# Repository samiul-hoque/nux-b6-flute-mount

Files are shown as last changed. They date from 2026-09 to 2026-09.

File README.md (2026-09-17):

# NUX B-6 flute mount

3D printed clamps that mount a **NUX B-6** or **B-6 Pro** wireless microphone onto a
flute or tin whistle.

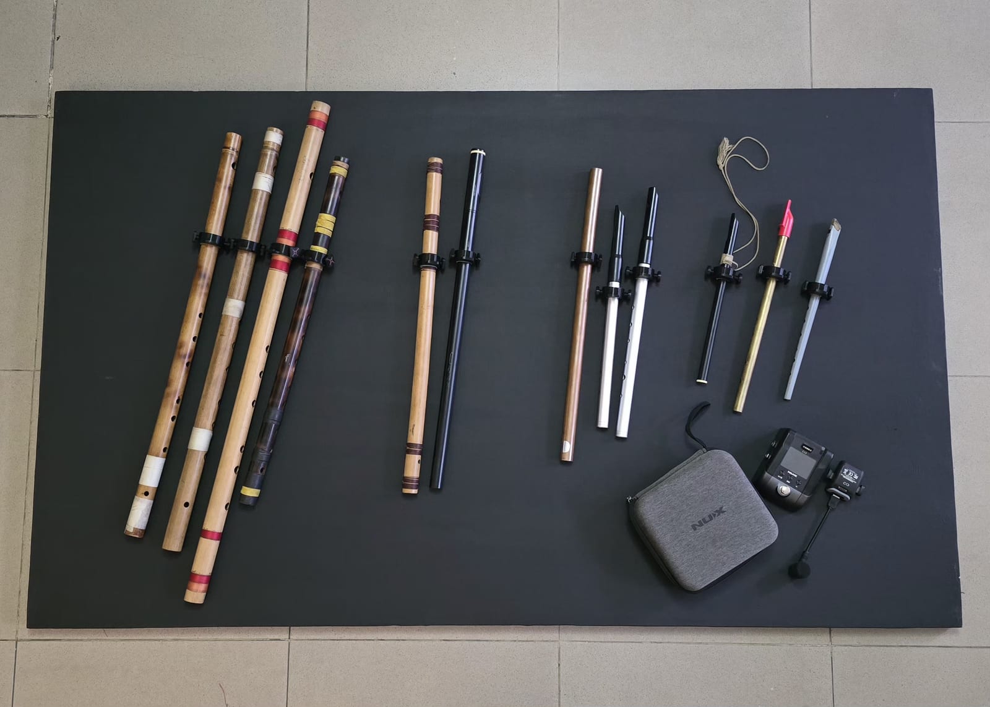
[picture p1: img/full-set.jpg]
Thirteen flutes with clamps fitted, alongside the NUX B-6 case and transmitter


*The set this was built for: thirteen flutes in bamboo, aluminium, copper, brass and
resin, each with a clamp fitted, and the B-6 kit bottom right.*

The B-6 is sold for saxophone. It expects to clamp onto a bell: a rigid flared metal mouth
of one known size. A flute is a straight tube, and if you play one there is nothing on the
instrument for the mic to hold. These parts sit between the two.

The clamp is in two layers, which is the whole idea:

- a **rigid PETG split ring** that carries the standard B-6 clip and provides the clamping
  force, closed with a printed thumb screw that threads straight into the ring
- a **flexible TPU spacer** that takes up the difference between the clamp bore and your
  actual tube, and grips without marking the instrument

| | |
| --- | --- |
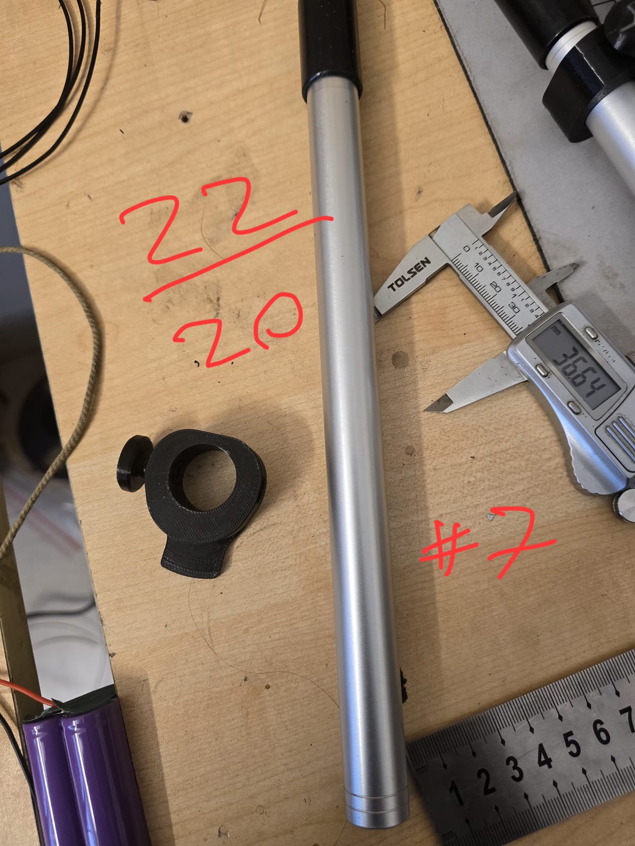
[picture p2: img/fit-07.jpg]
The printed clamp on its own, on a workbench beside an aluminium flute and callipers
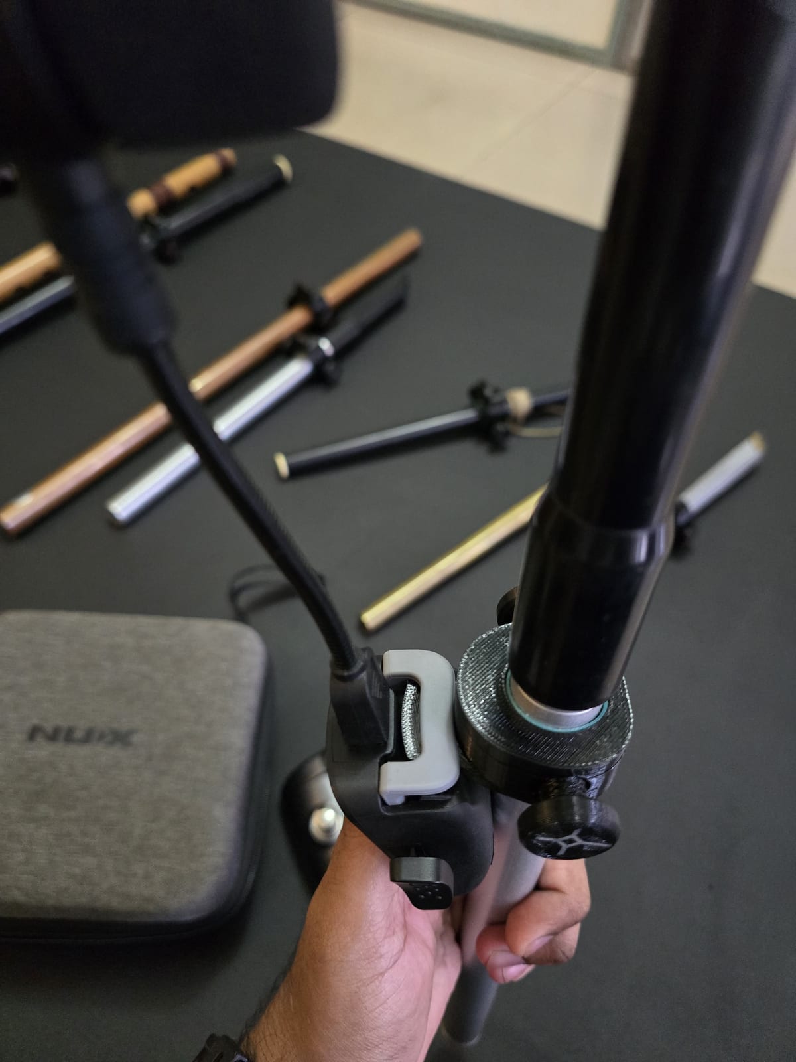
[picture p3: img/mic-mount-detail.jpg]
Close view of the clamp holding the NUX mic clip with the TPU spacer visible inside the bore
|  |  |
| The rigid part on its own: split ring, mic boss underneath, printed thumb screw. | Assembled. The pale ring inside the bore is the TPU spacer; the boss takes the B-6 clip. |

Keeping those separate is what makes one clamp cover several flutes. A rigid clamp
tightened straight onto a bamboo flute would slip or dent it, and onto a thin aluminium
tube it would crush it. The TPU does the conforming so the PETG does not have to.

Built in a day for Nazm Anwr, who plays flute for the Bangladeshi band
[Kaaktaal](https://samiulmakes.com/projects/flute-mic-clamps/), because he performs with
thirteen flutes and swaps between them mid-set. The screws are printed too: no hardware
run, nothing metal to lose in a green room, and a thumb screw big enough to turn by hand
between songs.

Full write-up, with photos of the whole set:
**<https://samiulmakes.com/projects/flute-mic-clamps/>**

## Sizes

Five clamp bores, ten spacers. Pick the clamp that fits over your flute, then the spacer
that brings it down to your diameter.

| Clamp bore | Spacer inner diameters |
| --- | --- |
| 22 mm | 15, 16, 20 |
| 24 mm | 22, 22.5 |
| 28 mm | 24.5, 26.5 |
| 30 mm | 27.5 |
| 35 mm | 30, 33 |

Measure your flute with callipers at the point you want the mic to sit, which is usually
just below the embouchure hole and clear of the finger holes.

## Instruments these have been fitted to

The set these were built for is mostly handmade bamboo, which has no model number. The
shop-bought instruments in it do:

| Instrument | Material |
| --- | --- |
| Tony Dixon DX207, key of A | Aluminium |
| Tony Dixon DX207, key of G | Aluminium |
| Tony Dixon TB014 tenor flute | Polymer |
| Tony Dixon DX001 soprano whistle | Polymer |
| Generation whistle, key of Eb | Brass |
| Clarke whistle, key of C | Tin |

If you play one of these, a clamp and spacer from this repo has been fitted to that exact
instrument. **Measure yours before printing anyway.** The pairings were recorded per flute
during the fitting session, not per model, so there is no "a DX207 takes 22 over 20" list
to give you — and tube stock changes between production runs.

## If your flute is between sizes

You need a **new spacer, not a new clamp**. Take the clamp bore above your diameter, open
the CAD, change the spacer's inner diameter, print it. That is a one-parameter change and
a few minutes of printing.

Which is the reason the source file is here and not just the STLs.

## Printing

| Part | Material | Layer height | Walls |
| --- | --- | --- | --- |
| Clamp shells | PETG | 0.2 mm | 4 |
| Thumb screws | PETG | 0.2 mm | 4 |
| Spacers | TPU | 0.2 mm | — |

Four walls on the PETG is the one setting worth keeping. The clamp is a split ring that
gets tightened onto an instrument, so the load runs straight through the wall either side
of the screw; thin walls there are where it would fail. The originals have been through a
live set and are still in use on these settings.

Everything else is whatever your printer likes. Print the screws standing on their heads,
threads upward, so the thread does not need support.

<!-- TODO (Samiul): infill and TPU shore hardness still not recorded. -->

## Fasteners

The clamp closes with printed thumb screws, in three shank lengths:

| Part | Shank |
| --- | --- |
| `screw-6mm.stl` | 6 mm |
| `screw-8mm.stl` | 8 mm |
| `screw-10mm.stl` | 10 mm |

All three share the same head: a 20 mm disc, 5 mm thick, with knurl lobes standing out to
25 mm so it can be turned with cold fingers. The thread is a printed one, roughly 10 mm
across, not an M-series profile — these mate with the clamps here and with nothing else.

There is no nut. The thread is cut into the clamp itself, so the screw is the only
fastener you print.

Longer shanks are for the bigger bores, where the split has further to close. If you are
unsure, print the 8 mm first.

## Files

`cad/flute-adapter-v19.f3d` — the parametric Fusion 360 source for the clamps and
spacers, and the file you want if your flute is not on the list.

`cad/screws-v5.f3d` — the Fusion source for the thumb screws.

`stl/` — 18 parts, ready to print:

| Clamp | Spacers |
| --- | --- |
| `clamp-22mm.stl` | `spacer-22-to-15mm.stl`, `spacer-22-to-16mm.stl`, `spacer-22-to-20mm.stl` |
| `clamp-24mm.stl` | `spacer-24-to-22mm.stl`, `spacer-24-to-22.5mm.stl` |
| `clamp-28mm.stl` | `spacer-28-to-24.5mm.stl`, `spacer-28-to-26.5mm.stl` |
| `clamp-30mm.stl` | `spacer-30-to-27.5mm.stl` |
| `clamp-35mm.stl` | `spacer-35-to-30mm.stl`, `spacer-35-to-33mm.stl` |

Plus three thumb screws — `screw-6mm.stl`, `screw-8mm.stl`, `screw-10mm.stl` — which fit
every clamp. See [Fasteners](#fasteners).

Every spacer is 18 mm tall, so it sits fully inside the clamp it belongs to. A spacer only
fits its own clamp; the outer profile changes with the bore.

## Licence

[Creative Commons Attribution 4.0 International](LICENSE) (CC BY 4.0).

Use these however you like — print them, sell the prints, modify the CAD, put the
modified version out yourself — as long as you credit me. Something along these lines is
enough:

> Flute mic clamps for the NUX B-6 by [Samiul Hoque](https://samiulmakes.com), licensed
> CC BY 4.0. <https://github.com/samiul-hoque/nux-b6-flute-mount>

If you remix them, say what you changed, so nobody chasing a bad fit ends up at my door
over someone else's edit.

## In use

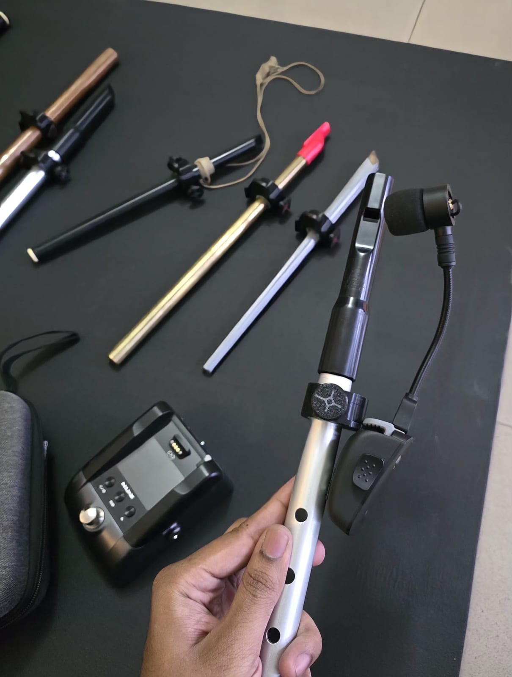
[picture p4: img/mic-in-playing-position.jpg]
A small aluminium flute held in playing position with the clamp, transmitter and gooseneck mic mounted


*The mic head sitting where it needs to sit, on a flute that had nowhere to mount
anything. These held up through a live set and are still in use.*

## Credits

Designed by [Samiul Hoque](https://samiulmakes.com) with Nazm Anwr.
NUX and B-6 are trademarks of their respective owner; this project is not affiliated with
or endorsed by NUX.

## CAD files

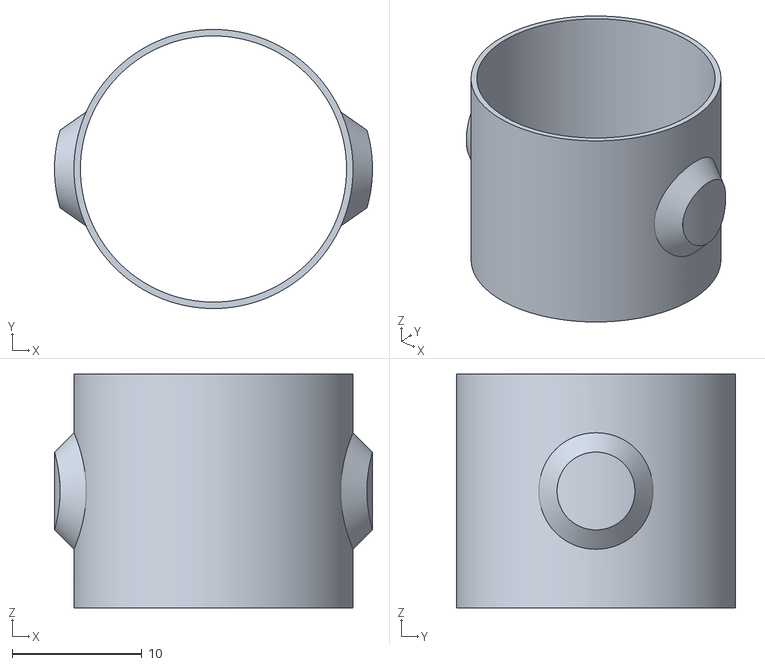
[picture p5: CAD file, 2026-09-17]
stl/spacer-22-to-20mm.stl
24.5 x 21.5 x 18.0

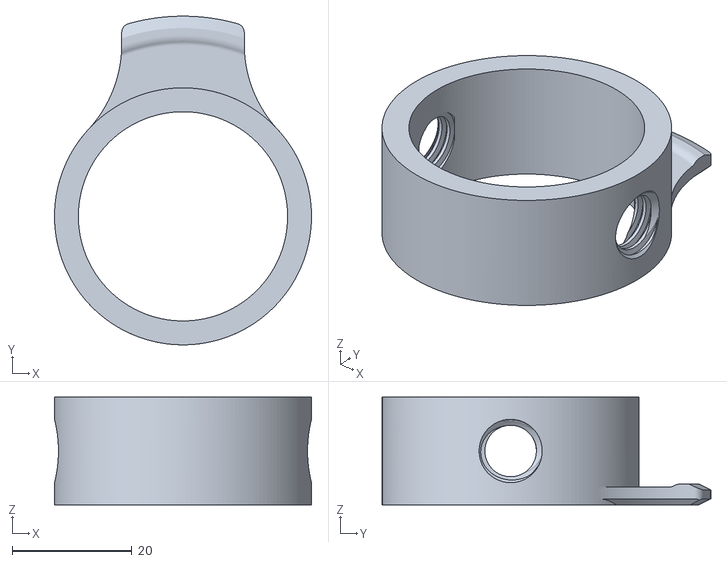
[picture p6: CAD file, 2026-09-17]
stl/clamp-35mm.stl
43.0 x 55.0 x 18.0

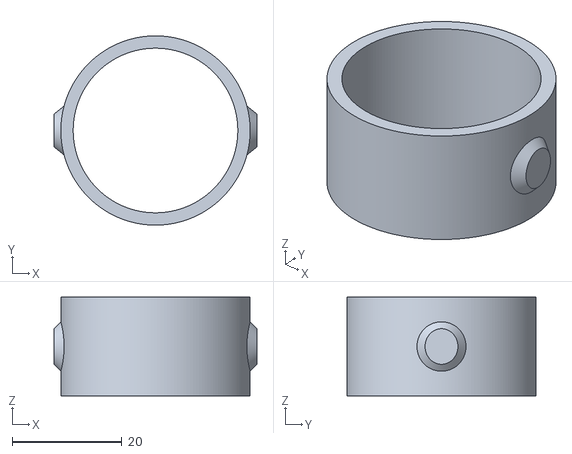
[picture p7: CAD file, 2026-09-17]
stl/spacer-35-to-30mm.stl
37.0 x 34.5 x 18.0

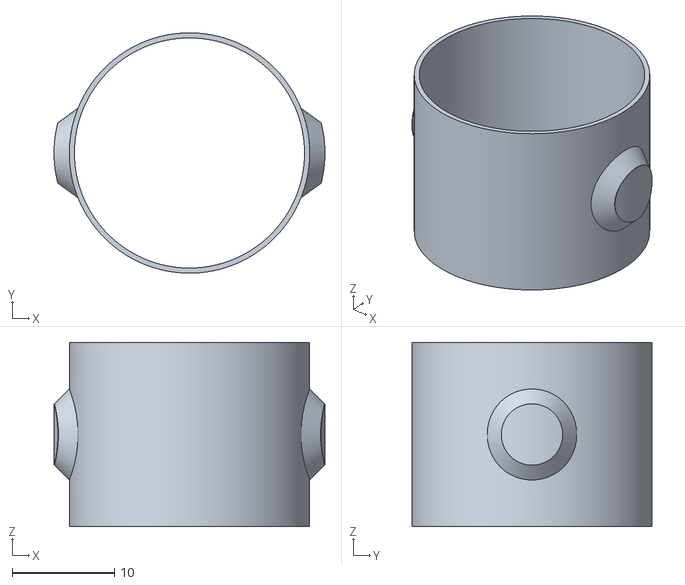
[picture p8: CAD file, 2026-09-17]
stl/spacer-24-to-22.5mm.stl
26.5 x 23.5 x 18.0

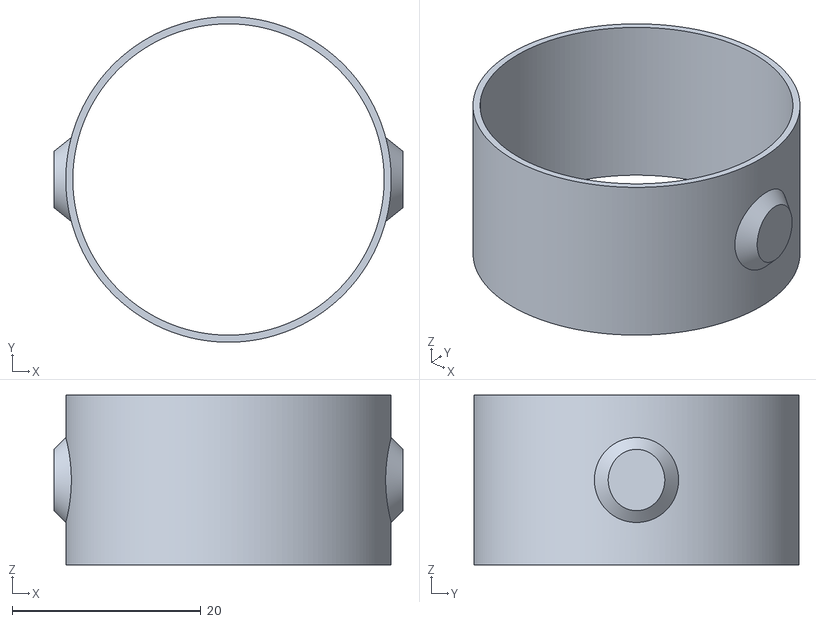
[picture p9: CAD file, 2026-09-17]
stl/spacer-35-to-33mm.stl
37.0 x 34.5 x 18.0

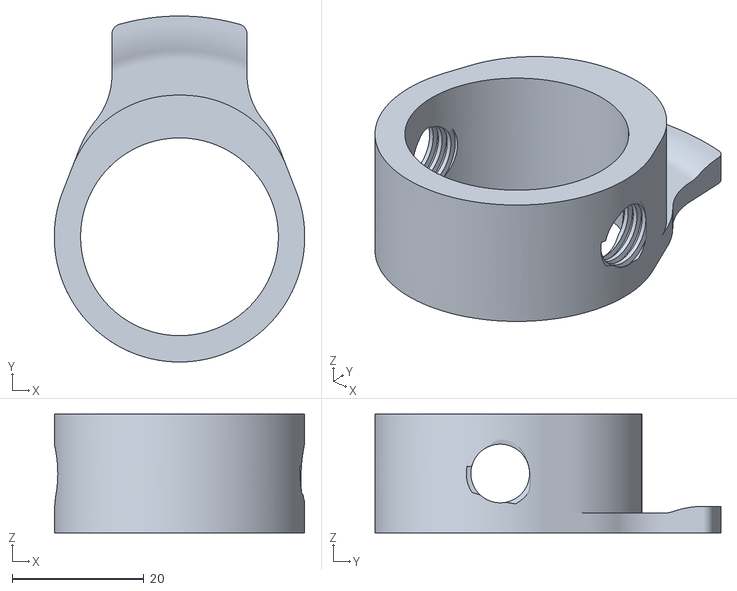
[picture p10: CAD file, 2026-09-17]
stl/clamp-30mm.stl
38.0 x 52.5 x 18.0

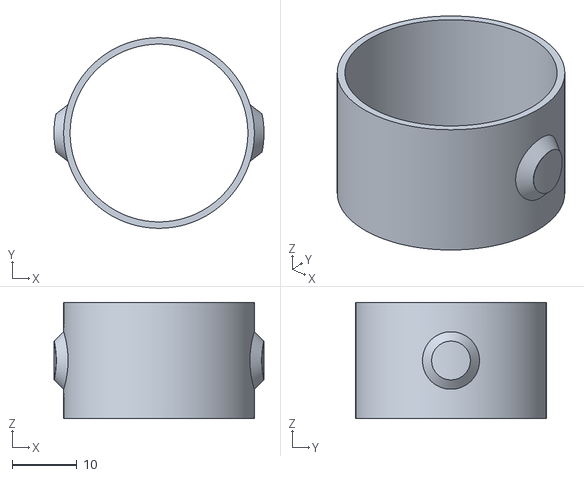
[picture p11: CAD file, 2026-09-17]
stl/spacer-30-to-27.5mm.stl
32.5 x 29.5 x 18.0

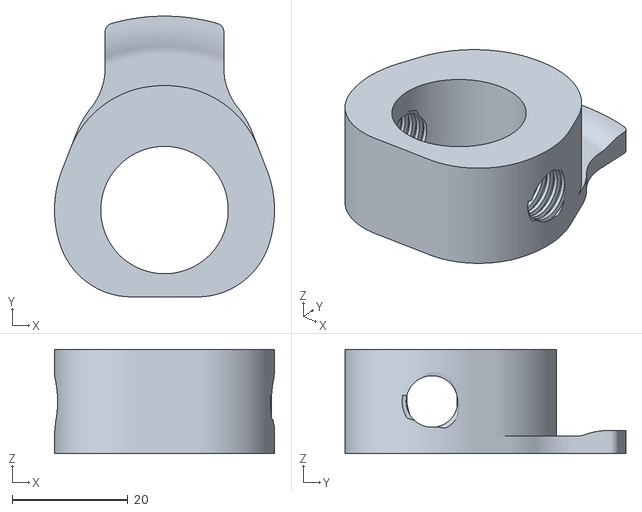
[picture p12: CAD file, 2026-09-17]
stl/clamp-22mm.stl
38.0 x 48.5 x 18.0

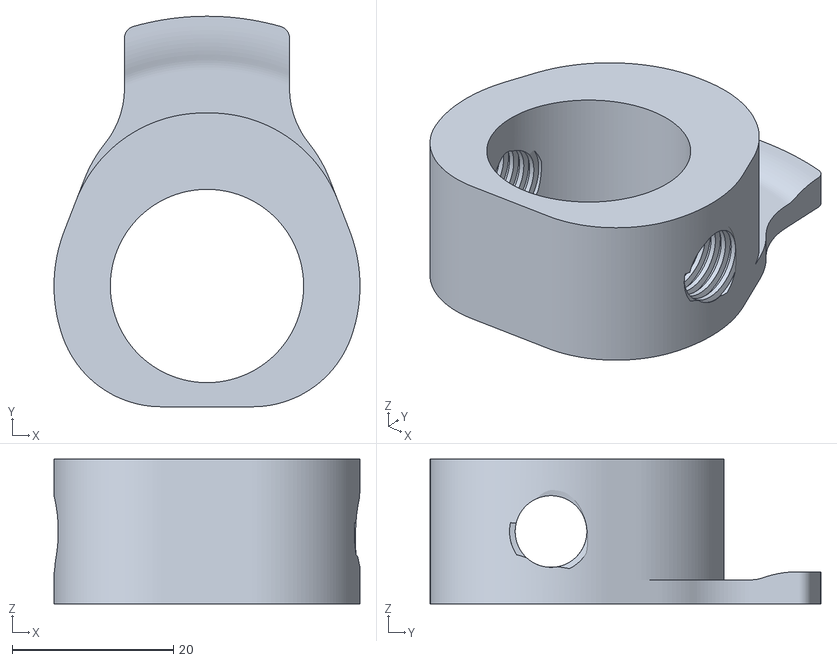
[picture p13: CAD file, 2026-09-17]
stl/clamp-24mm.stl
38.0 x 48.5 x 18.0

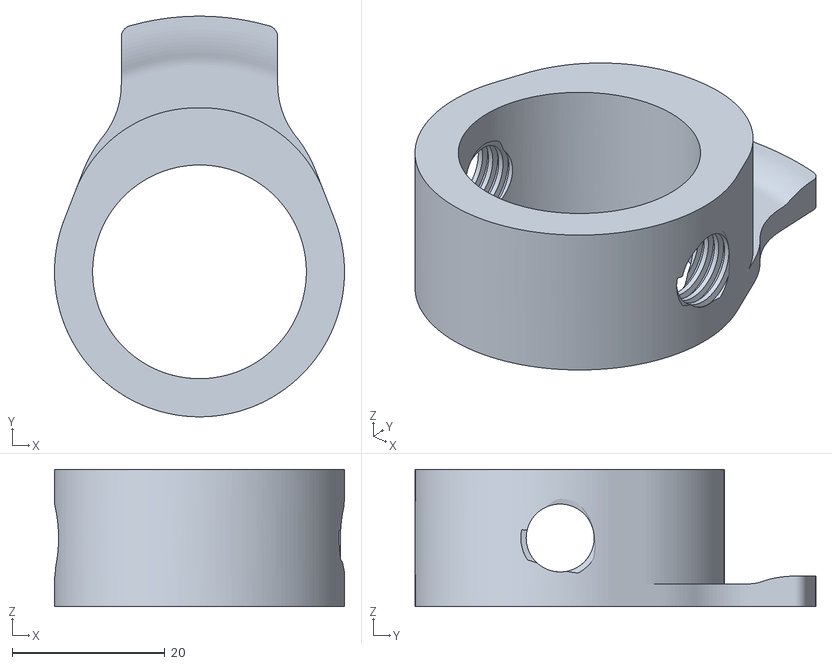
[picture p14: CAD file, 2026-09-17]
stl/clamp-28mm.stl
38.0 x 52.5 x 18.0

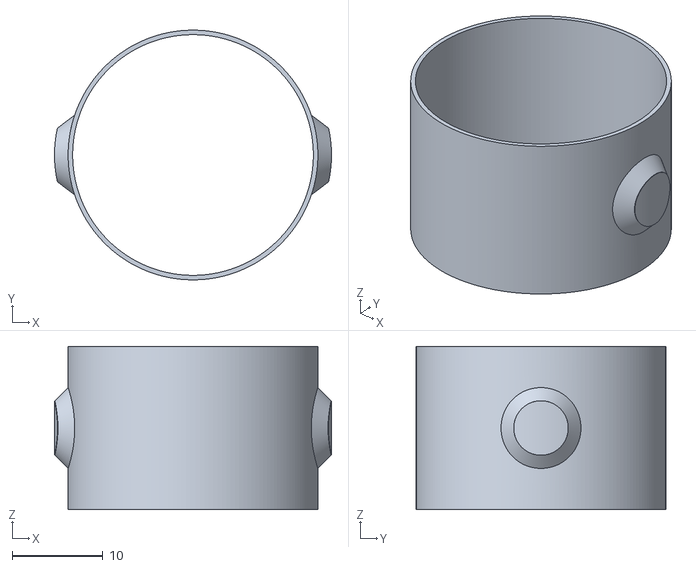
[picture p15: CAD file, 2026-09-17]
stl/spacer-28-to-26.5mm.stl
30.5 x 27.5 x 18.0

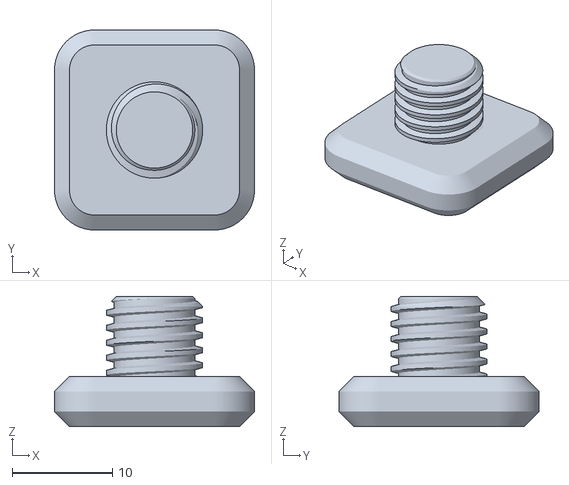
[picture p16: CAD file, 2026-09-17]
stl/screw-8mm.stl
20.0 x 20.0 x 13.0

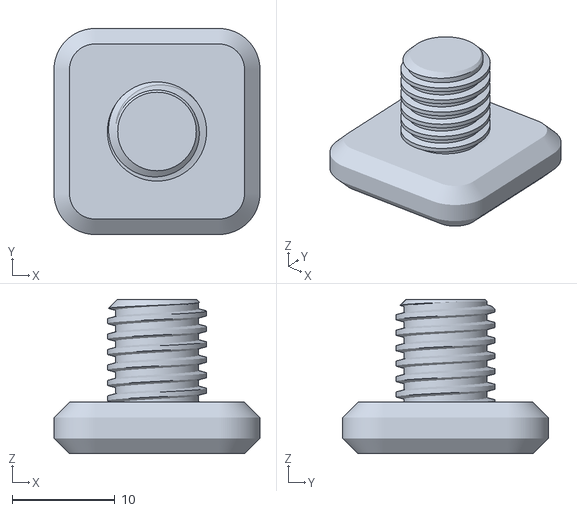
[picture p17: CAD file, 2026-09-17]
stl/screw-10mm.stl
20.0 x 20.0 x 15.0

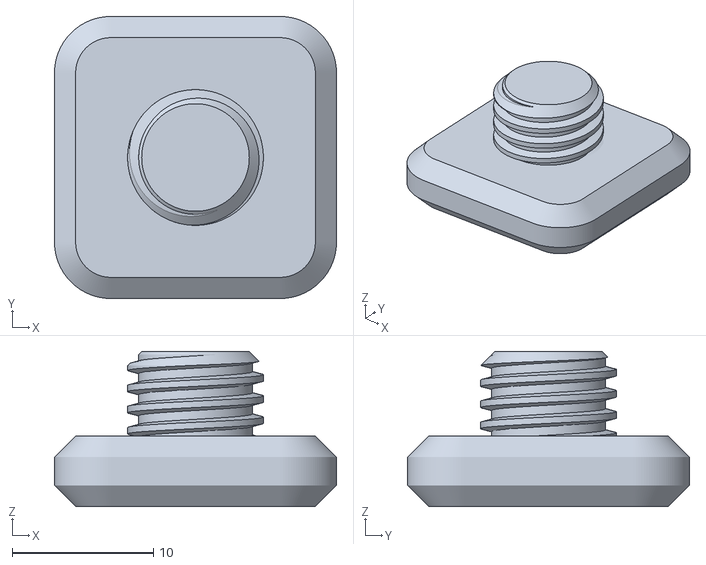
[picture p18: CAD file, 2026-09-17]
stl/screw-6mm.stl
20.0 x 20.0 x 11.0

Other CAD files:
stl/spacer-22-to-16mm.stl
stl/spacer-24-to-22mm.stl
stl/spacer-22-to-15mm.stl
stl/spacer-28-to-24.5mm.stl
cad/flute-adapter-v19.f3d
cad/screws-v5.f3d

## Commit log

2026-09-17 Scaffold: README, folder structure, drop folder
    Structure and copy are in place so that adding the actual files is a
    single commit. README carries the bore/spacer table and the point that a
    between-sizes flute needs a new spacer rather than a new clamp, which is
    why the parametric source is published and not only the STLs.
    Print settings and licence are left as TODOs rather than guessed at.
2026-09-17 Add the STLs and the Fusion source
    15 parts: five clamp bores and ten spacers, renamed so each filename
    says its bore and its target diameter. The originals arrived grouped by
    bore with mixed naming, and the 35 mm parts were sitting in the 30 mm
    folder, which the geometry confirmed: clamp-35mm is 43x55 where the
    others are 38 wide, and its spacers are 37x34.5 where the 30 mm ones are
    32.5x29.5.
    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
    [clamp-22mm.stl, clamp-24mm.stl, clamp-28mm.stl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]
2026-09-17 Add photos from the project write-up to the README
    Four images: the full set, the clamp on its own, the assembly showing
    the TPU spacer inside the bore, and one in playing position. Committed
    into the repo rather than hotlinked from the site, so the README does
    not break if the site moves.
2026-09-17 Add the printed thumb screws and their Fusion source
    Three shank lengths (6, 8, 10 mm) sharing a 20 mm knurled head, exported
    from Screws v5. Drops the README's "fasteners are not in this repo yet"
    notes and documents the three parts instead.
    The nuts still are not here — only the screws came across — so that stays
    as a TODO in the Fasteners section.
    Claude-Session: https://claude.ai/code/session_016ytrq6Wgwk3cUzck38fEY1
    [screw-10mm.stl, screw-6mm.stl, screw-8mm.stl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]
2026-09-17 Correct the README: the clamp is threaded, there is no nut
    The screw threads straight into the split ring. Drops the leftover nut
    TODO and the "screws and nuts" phrasing in the intro.
    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
2026-09-17 Name the shop-bought instruments the clamps were fitted to
    Two Tony Dixon DX207s (A and G), a TB014 tenor, a DX001 soprano whistle,
    a Generation Eb and a Clarke C. Anyone searching one of those models can
    now find these parts. Notes that the pairings were recorded per flute
    rather than per model, so it is still measure-before-you-print.
    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
2026-09-17 Add the CC BY 4.0 licence and the print settings
    Licence is plain CC BY: free to use, modify and sell, with credit. Full
    legal code in LICENSE, with a ready-made attribution line in the README.
    Print settings are the ones the originals were made on: 0.2 mm throughout,
    four walls on the PETG parts. Infill and TPU shore hardness were not
    recorded, so those stay open.
    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
